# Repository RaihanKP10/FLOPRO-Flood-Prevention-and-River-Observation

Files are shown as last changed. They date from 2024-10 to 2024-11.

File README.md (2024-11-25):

# FLOPRO : Flood Prevention and River Observation

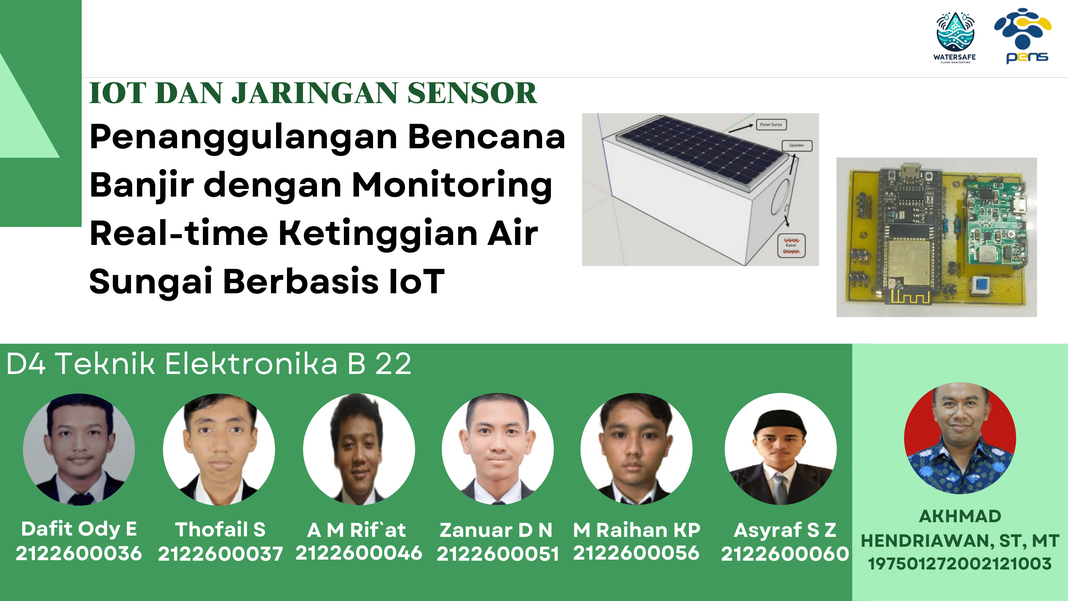
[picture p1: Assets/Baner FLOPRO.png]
Logo FLOPRO


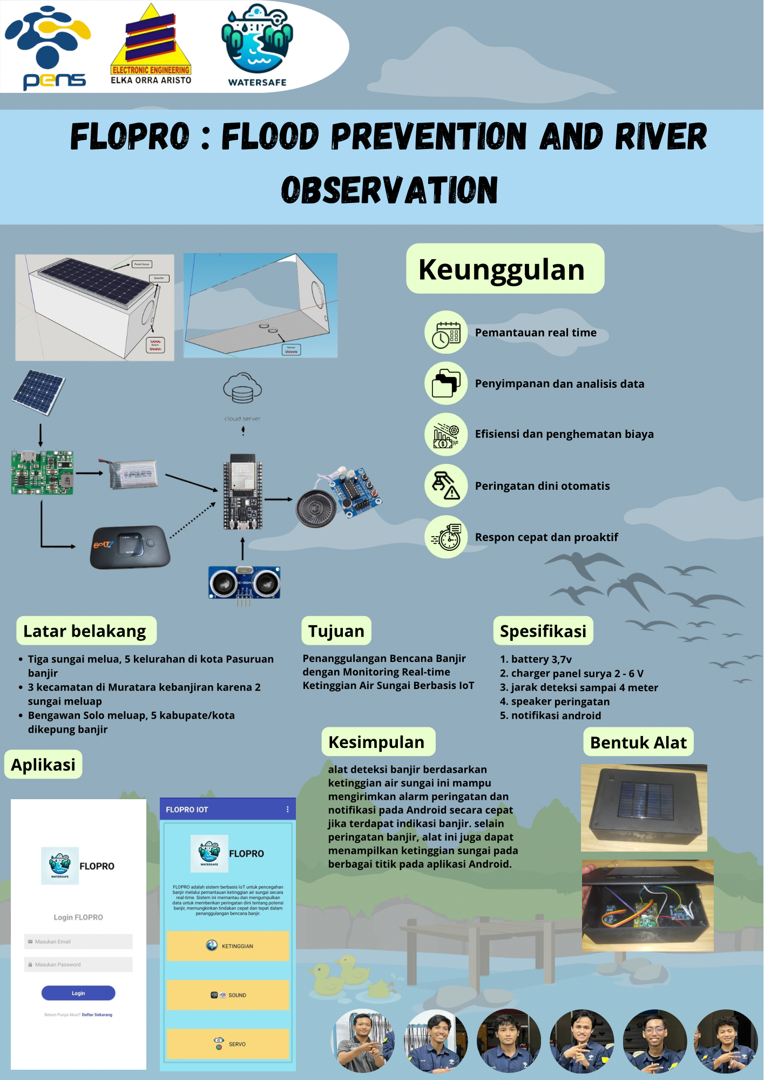
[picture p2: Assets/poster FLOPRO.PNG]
Logo FLOPRO


Proyek ini adalah Sistem Pemantauan Ketinggian Air Sungai yang menggunakan teknologi IoT untuk memberikan peringatan banjir secara real-time dengan mengukur ketinggian air sungai. Sistem ini dirancang untuk membantu manajemen bencana banjir dengan memberikan notifikasi kepada pemerintah daerah dan masyarakat tentang peningkatan ketinggian air, sehingga tindakan pencegahan dapat dilakukan sebelum banjir terjadi.

IoT dan Jaringan Sensor - [PROGRAM STUDI TEKNIK ELEKTRONIKA](https://elektronika.pens.ac.id/) - [POLITEKNIK ELEKTRONIKA NEGERI SURABAYA](https://www.pens.ac.id/)

`DOSEN PENGAMPU : Akhmad Hendriawan ST, MT`

`NIP. 197501272002121003`

## Daftar Isi
- [Fitur](https://github.com/RaihanKP10/FLOPRO-Flood-Prevention-and-River-Observation/blob/main/README.md#fitur)
- [Anggota Tim](https://github.com/RaihanKP10/FLOPRO-Flood-Prevention-and-River-Observation/blob/main/README.md#anggota-tim)
- [Demonstrasi Kalibrasi Sensor](https://github.com/RaihanKP10/FLOPRO-Flood-Prevention-and-River-Observation/blob/main/README.md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)

## Fitur
- **Pemantauan Real-Time**: Mengukur ketinggian air sungai secara terus-menerus menggunakan sensor.
- **Transmisi Data**: Mengirimkan data ke server cloud melalui perangkat IoT.
- **Sistem Peringatan Banjir**: Memberikan peringatan ketika ketinggian air melebihi ambang batas.
- **Antarmuka Web dan Mobile**: Menampilkan data dan peringatan pada dasbor yang mudah digunakan.
- **Penyimpanan Data**: Menyimpan data untuk analisis dan prediksi.
- **Pengaturan Ambang Batas**: Menyesuaikan ambang batas sesuai tingkat risiko.

## Anggota Tim

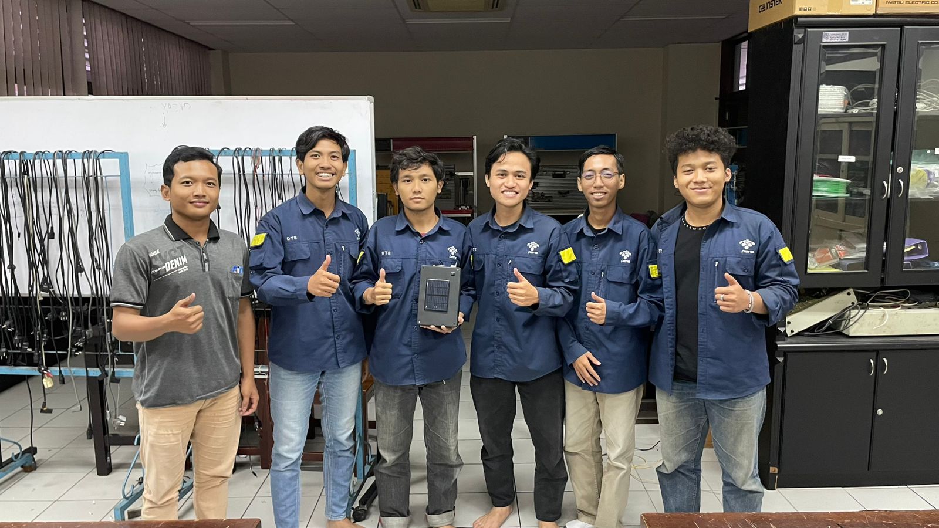
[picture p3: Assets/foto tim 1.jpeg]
FotoTim

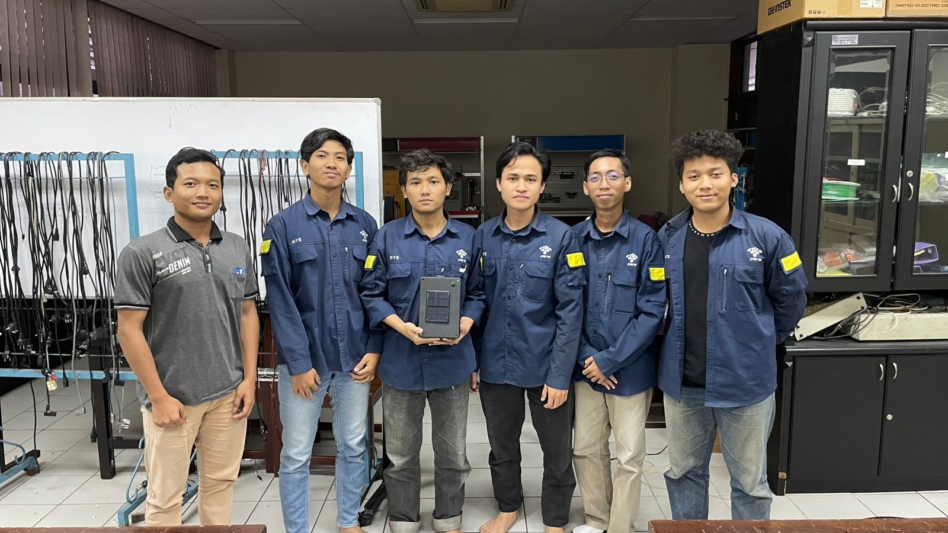
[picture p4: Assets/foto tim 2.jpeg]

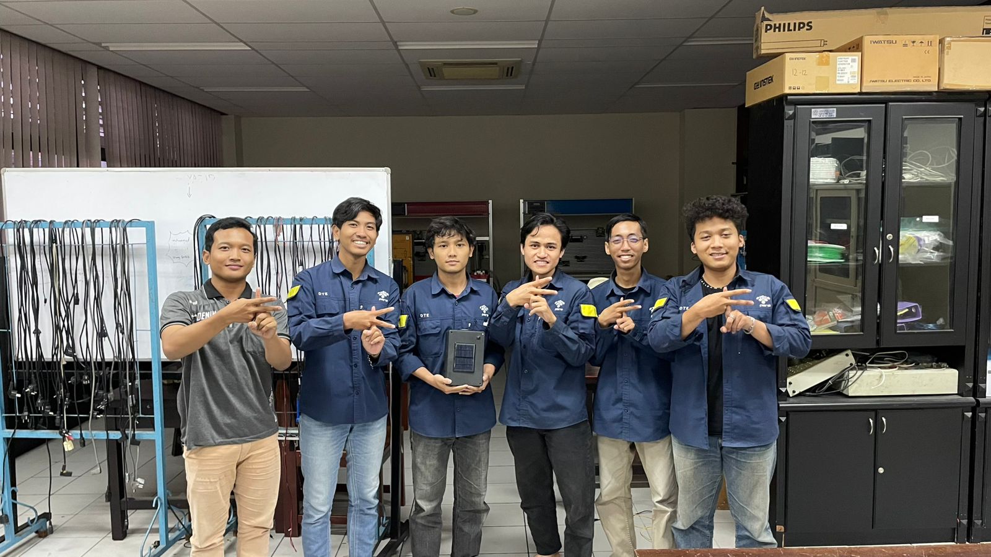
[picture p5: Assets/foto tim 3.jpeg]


| Foto | NRP | Nama | Jobdesk | Akun |
|---|---|---|---|---|
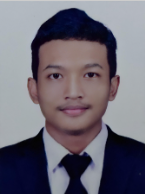
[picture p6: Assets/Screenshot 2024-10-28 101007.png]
Foto Ody
|  | 2122600036 | Dafit Ody Endriantono | UI/UX Designer | [Ody](https://github.com/DafitOdy-In) |
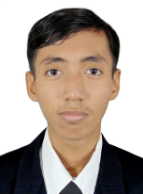
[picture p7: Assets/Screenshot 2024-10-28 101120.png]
Foto Thofail
|  | 2122600037 | Thofail Syakirudin | Hardware | [Thofail](https://github.com/DzavanTS) |
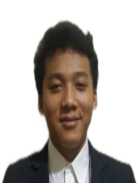
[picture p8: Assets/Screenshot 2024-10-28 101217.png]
Foto Rif'at
|  | 2122600046 | Ahmad Miftahur Rif'at | Mechanical | [Rif'at](https://github.com/AatForUX) |
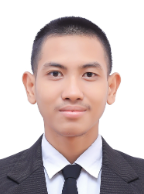
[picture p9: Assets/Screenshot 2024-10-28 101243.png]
Foto Zanuar
|  | 2122600051 | Zanuar Dwi Novaliyanto | Mechanical | [Zanuar](https://github.com/ZanuarDwiNovaliyanto) |
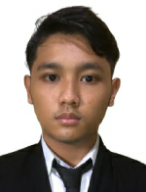
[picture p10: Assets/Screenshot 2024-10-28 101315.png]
Foto Raihan
|  | 2122600056 | Moch Raihan Kemal P | Software | [Raihan](https://github.com/RaihanKP10) |
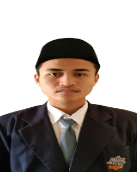
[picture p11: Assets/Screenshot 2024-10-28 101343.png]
Foto Asyraf
|  | 2122600060 | Asyraf Sulthan Zaky | Project Manager | [Asyraf](https://github.com/AsyrafSinclair) |

## Hardware Desain
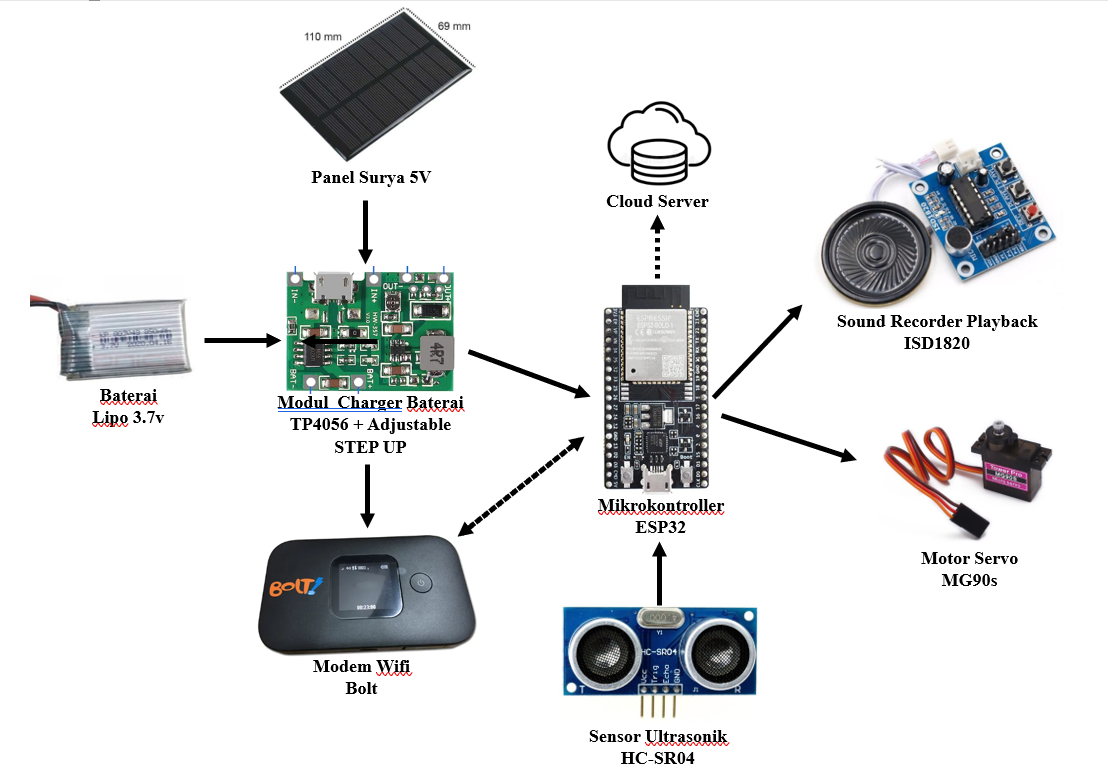
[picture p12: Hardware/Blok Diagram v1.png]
Desain Hardware


Alat ini mengukur ketinggian air dengan sensor ultrasonik HCSR-04 dan mengirimkan data ke server untuk ditampilkan melalui aplikasi. Ketika ketinggian mendekati ambang batas, sistem memicu servo untuk membuka pintu air di bendungan. Karena alat berada di luar ruangan, data dikirim melalui modem WiFi, dan energi diperoleh dari panel surya mini yang disimpan dalam baterai.

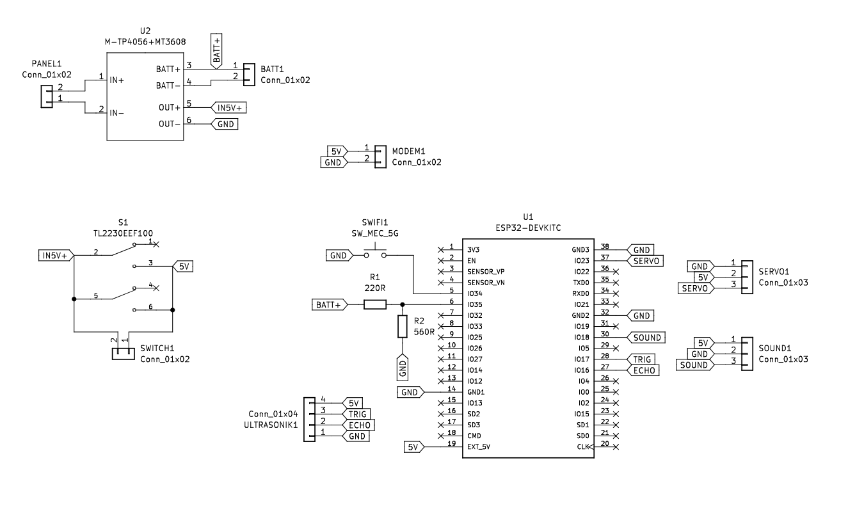
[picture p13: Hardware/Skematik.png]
Hardware Skematik Desain

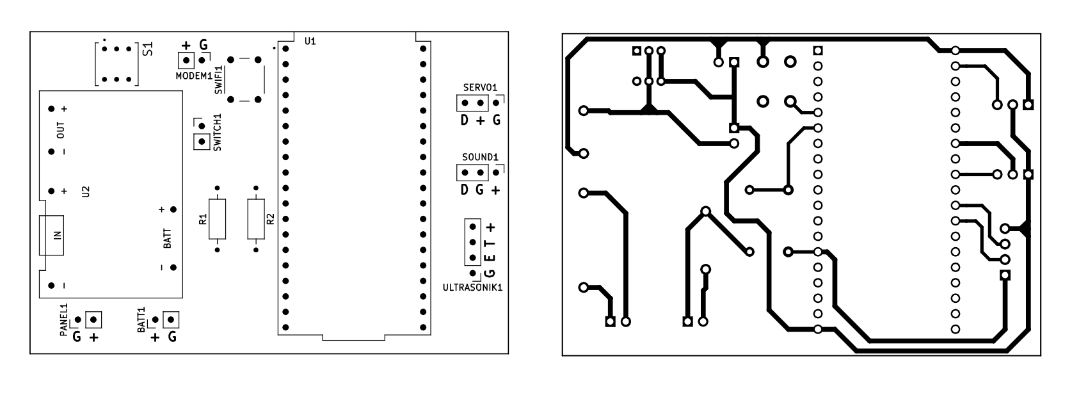
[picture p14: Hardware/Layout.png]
Hardware Layout Desain

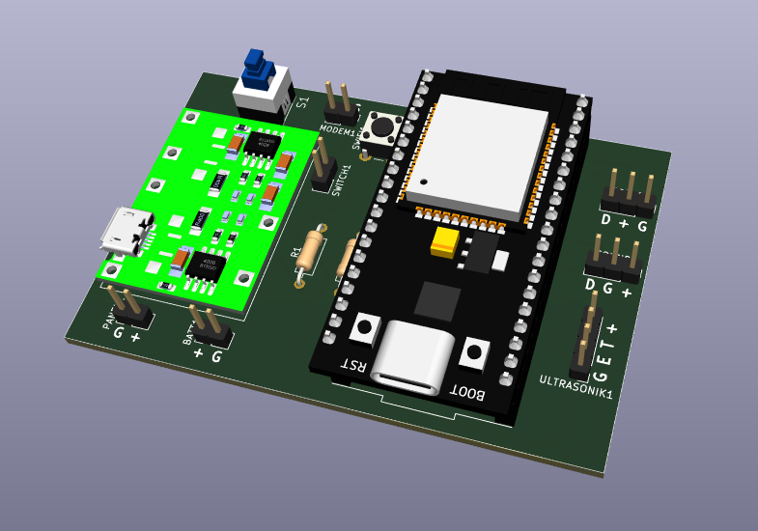
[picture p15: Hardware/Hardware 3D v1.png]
Desain 3D Hardware

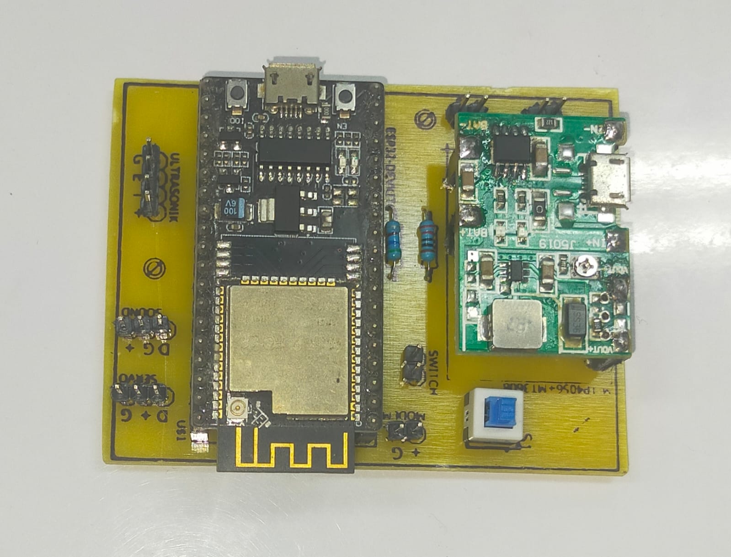
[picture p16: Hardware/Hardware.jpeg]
Desain Hardware


---

---
## PPT FLOPRO

https://www.canva.com/design/DAGU0XxpfDs/OkEMPqyUYkoWt_qYXgOqGQ/edit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

---

---

## Demonstrasi Kalibrasi Sensor
#### 1. Link Demonstrasi Kalibrasi Sensor HCSR04 :

https://github.com/user-attachments/assets/5eed2dfb-3297-49b0-9c64-bf10c1c43c4e
   
https://youtube.com/shorts/4SDvYGCIjRk?feature=share
   
Kalibrasi sensor HC-SR04 adalah proses penyesuaian sensor ultrasonik ini untuk meningkatkan akurasi dalam mengukur jarak. Sensor HC-SR04 bekerja dengan mengirimkan gelombang ultrasonik dari pemancar (transmitter) dan menghitung waktu yang dibutuhkan oleh gelombang tersebut untuk memantul kembali ke penerima (receiver) setelah mengenai suatu objek. Dengan menggunakan kecepatan suara sebagai acuan, sensor ini dapat menghitung jarak objek berdasarkan waktu tempuh gelombang.

#### 2. Link Demonstrasi Kalibrasi Servo MG90s :

https://github.com/user-attachments/assets/9af5d12e-d331-4dda-a720-6778b383e7d6
   
https://youtube.com/shorts/B2ZGl9izdCo?feature=share
   
Kalibrasi servo MG90S adalah proses penyetelan servo motor ini untuk memastikan bahwa sudut putarannya akurat sesuai dengan sinyal kontrol yang diterima. Servo MG90S adalah servo motor kecil yang banyak digunakan dalam proyek robotika dan sistem kontrol, dengan kemampuan untuk berputar pada sudut tertentu berdasarkan sinyal PWM (Pulse Width Modulation) yang diterimanya.

#### 3. Link Demonstrasi Kalibrasi Mini Speaker :

https://github.com/user-attachments/assets/9ce2ebc6-c74e-48cd-b972-0ce2e92cbb17
   
https://youtu.be/lZPbhcjN7L0
   
Kalibrasi mini speaker adalah proses penyesuaian output suara dari speaker kecil untuk mencapai kualitas audio yang optimal sesuai kebutuhan. Mini speaker sering digunakan dalam perangkat elektronik portabel dan sistem suara kecil. Kalibrasi pada mini speaker bertujuan untuk memastikan bahwa suara yang dihasilkan sesuai dengan frekuensi yang diinginkan, volume yang tepat, serta tanpa distorsi.

#### 4. Link Demonstrasi Koneksi OTA :

https://github.com/user-attachments/assets/de8e1125-ee2f-4111-9aa6-75a2dc0249be

https://youtu.be/pMJeovFwK_Y?si=bnQbwsUD5YesixBR

Demonstrasi Koneksi OTA (Over-the-Air): Pada bagian pertama, kita akan melihat langkah-langkah dalam mengatur koneksi OTA. Ini memungkinkan perangkat untuk menerima pembaruan firmware secara nirkabel, memudahkan Anda mengelola pembaruan sistem tanpa perlu koneksi fisik ke perangkat.

#### 5. Link Demonstrasi Pembuatan Firmware :

https://github.com/user-attachments/assets/bfa29fa6-aab0-4fcf-a872-c59f6ed02e61

https://youtu.be/gWfn4EX8Wdg?si=ucNGiH2ZgVsit7tk

Demonstrasi Pembuatan Firmware: Berikutnya, kita akan mendalami proses pembuatan firmware yang sesuai dengan perangkat IoT Anda. Di sini, kita akan membahas cara menyusun kode, mengompilasi, hingga mengunggah firmware yang telah dibuat.

#### 6. Link Demonstrasi Sistem Monitoring Baterai :

https://github.com/user-attachments/assets/31b2b31e-45c3-4f26-8fa8-c767af66bc61

https://youtu.be/-h_9dVcLRwE?si=lmYOK9LiICJJzn_O

Demonstrasi Sistem Monitoring Baterai: Terakhir, kita akan mengimplementasikan sistem monitoring baterai untuk memantau status baterai perangkat. Monitoring ini sangat penting agar kita dapat memprediksi daya tahan perangkat dan memastikan bahwa perangkat selalu aktif sesuai kebutuhan.

#### 7. Link Demonstrasi Wifi Manager:

https://github.com/user-attachments/assets/3f8c9bdd-fb43-4b81-9738-53641b77a450

https://youtu.be/Md__u2JPdc4?si=srvmaIoYwEQb-n4l

Konfigurasi Wifi Manager FLOPRO untuk Proyek IoT dan Jaringan Sensor: Bagian pertama tutorial ini akan mengulas proses konfigurasi Wifi Manager untuk perangkat FLOPRO. Langkah ini penting agar perangkat dapat terhubung dengan jaringan WiFi yang ada secara fleksibel dan otomatis, memungkinkan koneksi yang efisien di berbagai lokasi.

#### 8. Link Demonstrasi Simulasi FLOPRO Pada Bak Mandi (Mengilustrasikan Sungai) :

https://github.com/user-attachments/assets/f5d06698-10ce-430e-9a92-0ce6799bd68e

https://youtu.be/32SNqkH3HE4?si=-2HCcUrE732MUAwt

Simulasi Demo FLOPRO pada Bak Mandi (Mengilustrasikan Sungai): Di bagian kedua, kita akan melakukan simulasi dengan bak mandi sebagai representasi sungai untuk memperlihatkan bagaimana sistem FLOPRO bekerja dalam mengukur dan memantau kualitas air. Sistem ini menggunakan sensor untuk membaca data kualitas air secara real-time, yang nantinya dapat diakses dari jarak jauh.

#### 9. Link Demonstrasi Alat + Aplikasi FLOPRO :

https://github.com/user-attachments/assets/4c1feaa1-9933-437e-9100-74239c586628

https://youtu.be/wIVfHC5TFvU

Demonstrasi alat dan aplikasi FLOPRO menampilkan cara penggunaan dan fitur utama FLOPRO untuk mendukung aktivitas pengguna. Video ini menunjukkan langkah-langkah operasional alat, mulai dari instalasi hingga integrasi dengan aplikasi FLOPRO, yang memungkinkan kontrol dan pemantauan data secara real-time. Dengan demonstrasi ini, pengguna dapat memahami bagaimana FLOPRO bekerja secara praktis untuk meningkatkan efisiensi dan efektivitas alat FLOPRO

#### 10. Link Demonstrasi Aplikasi FLOPRO :

https://github.com/user-attachments/assets/227b0415-c697-41e6-8797-6734db90a10a

https://youtu.be/Y9suIjy_hSk

Demonstrasi aplikasi FLOPRO memperlihatkan fitur-fitur utama dan cara menggunakan aplikasi untuk memaksimalkan fungsinya. Video ini menjelaskan langkah-langkah cara daftar akun dan login akun, serta cara menggunakan aplikasi

---

---
## Tampilan Aplikasi FLOPRO
#### 1. Register :
Register

Tampilan aplikasi FLOPRO bagian Register dirancang untuk memudahkan pengguna baru dalam membuat akun dan mengakses layanan aplikasi. Di halaman ini, pengguna akan diminta untuk mengisi informasi dasar seperti nama, email, dan kata sandi. Tampilan yang sederhana dan intuitif memastikan proses registrasi berjalan cepat dan mudah. Ada juga tombol Submit untuk menyelesaikan proses pendaftaran serta petunjuk tambahan yang membantu pengguna dalam mengisi data dengan benar.

### 2. Login :
Login

Tampilan aplikasi FLOPRO bagian Login dirancang untuk memudahkan pengguna masuk ke akun mereka dengan cepat dan aman. Di halaman ini, terdapat kolom untuk memasukkan email dan kata sandi, dengan tombol Login untuk melanjutkan ke halaman utama aplikasi. Tampilan yang sederhana dan bersih membantu pengguna fokus saat mengisi informasi. Ada juga opsi Forgot Password bagi pengguna yang lupa kata sandi, serta pilihan untuk mendaftar bagi pengguna baru yang belum memiliki akun.

### 3. Dashboard :
Dashboard

Tampilan aplikasi FLOPRO pada bagian Dashboard memberikan akses cepat dan ringkas ke informasi utama serta fitur-fitur penting. Di halaman ini, pengguna dapat melihat ringkasan data secara real-time, status perangkat yang terhubung, serta grafik atau statistik yang relevan dengan aktivitas mereka. Dashboard dirancang dengan antarmuka yang intuitif dan visual yang menarik, sehingga memudahkan pengguna dalam memantau, mengontrol, dan mengakses fitur aplikasi lainnya. Navigasi yang sederhana memungkinkan pengguna untuk berpindah ke menu lain dengan mudah dan efisien.

### 4. Demo Aplikasi FLOPRO Pembacaan Data Sensor :
https://github.com/user-attachments/assets/2c82f72f-5ee5-42d2-a93c-78d115699a81

### 5. Demo Aplikasi FLOPRO Register & Login Akun :
https://github.com/user-attachments/assets/8cda75ff-3960-4abb-a7de-a9cabbc41a08

---

---
## Video Presentasi & Iklan FLOPRO
#### 1. Presentasi :
https://youtu.be/c4BK9ON1-bA?si=03641uwP3lWksoRz

Video ini menampilkan presentasi lengkap dari proyek IoT dan Jaringan Sensor dengan nama FLOPRO yang dikerjakan oleh tim mahasiswa D4 Teknik ELektronika B. Presentasi mencakup beberapa segmen utama:

Latar Belakang Proyek
Penjelasan awal tentang motivasi dan tujuan pembuatan alat ini. Proyek ini dirancang untuk mengatasi masalah tertentu dengan memanfaatkan teknologi IoT dan jaringan sensor.

Demo Hardware dan Aplikasi

Langkah-langkah instalasi dan penggunaan perangkat keras.
Tampilan langsung dari sensor yang digunakan dan bagaimana data dikumpulkan.
Demonstrasi aplikasi yang dikembangkan untuk memonitor data dari sensor secara real-time melalui platform IoT.
Penjelasan Isi GitHub

Struktur repositori GitHub yang menyimpan seluruh kode sumber dan dokumentasi proyek.
Penjelasan tentang file utama, cara kerja program, dan instruksi penggunaan yang tersedia di GitHub.

#### 2. Iklan :
https://youtube.com/shorts/QswNNAhAtY0?si=gQIX3H-hSb-66b26

Video ini menampilkan iklan produk dari proyek IoT dan Jaringan Sensor dengan nama FLOPRO_yang dikerjakan oleh tim mahasiswa D4 Teknik Elektronika B

&copy; 2024 FLOPRO. All rights reserved.

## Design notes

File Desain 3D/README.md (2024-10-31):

# Desain 3D FLOPRO

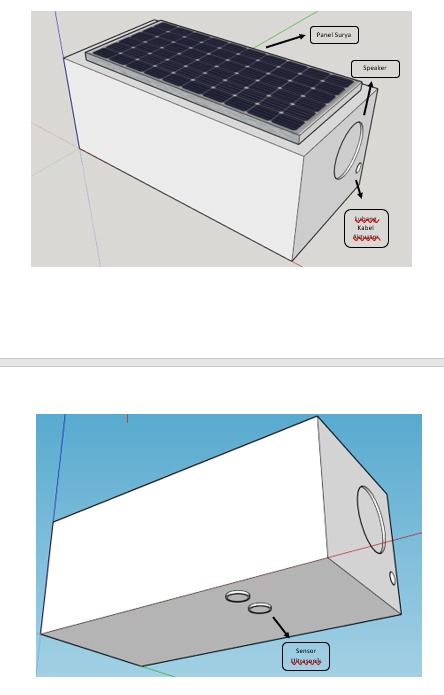
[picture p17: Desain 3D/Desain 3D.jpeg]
Desain 3D


Gambar yang ditampilkan menunjukkan desain perangkat berbentuk kotak yang dilengkapi dengan panel surya di bagian atas untuk sumber daya dan speaker di samping. Pada bagian bawah, terdapat sensor yang kemungkinan digunakan untuk mendeteksi parameter lingkungan seperti ketinggian air atau jarak, tergantung jenis sensornya. Desain perangkat ini memungkinkan sensor untuk melakukan pengukuran langsung terhadap permukaan di bawahnya. Dua lubang kecil di sekitar sensor mungkin berfungsi sebagai ventilasi atau akses untuk komponen lain. Kombinasi panel surya, sensor, dan speaker menunjukkan bahwa perangkat ini dirancang untuk pemantauan lingkungan secara mandiri.

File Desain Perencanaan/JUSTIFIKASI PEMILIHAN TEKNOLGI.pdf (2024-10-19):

JUSTIFIKASI PEMILIHAN TEKNOLGI

1. Sensor Ultrasonik HC-SR04
Sensor ini dipilih karena kemampuannya mengukur ketinggian air dengan cukup akurat menggunakan gelombang ultrasonik. HC-SR04 sangat sesuai untuk proyek ini karena ketahanannya terhadap kondisi lingkungan yang kurang ideal, seperti kelembaban dan hujan, sehingga memungkinkan pengukuran jarak secara stabil di berbagai kondisi.
2. Mikrokontroler ESP32
ESP32 dipilih karena memiliki fitur konektivitas Wi-Fi dan Bluetooth, serta daya pemrosesan yang lebih baik dibandingkan mikrokontroler lainnya, seperti ESP8266. Dengan dukungan Wi-Fi, ESP32 dapat mengirimkan data ketinggian air secara real-time ke server cloud, menjadikannya solusi ideal untuk pemantauan jarak jauh. Kemampuan ini penting dalam sistem monitoring yang memerlukan pengiriman data secara kontinu.
3. Protokol Komunikasi MQTT (Message Queuing Telemetry Transport)
Protokol MQTT digunakan untuk mengirimkan data ketinggian air secara efisien dan real-time. Protokol ini dipilih karena sifatnya yang ringan dan hemat energi, sehingga sangat cocok untuk perangkat seperti ESP32 yang sering beroperasi di lokasi yang sulit dijangkau dan memiliki keterbatasan daya.
4. Penyimpanan Cloud dengan MySQL
Data ketinggian air disimpan di cloud menggunakan database MySQL. MySQL menyediakan struktur penyimpanan data yang terorganisir, yang memudahkan akses serta analisis data historis.
5. Keamanan Data
Data yang dikirim dari ESP32 ke server cloud dienkripsi untuk menjaga keamanan dan melindungi informasi sensitif dari potensi ancaman atau serangan pihak luar.
6. Akses Melalui Antarmuka Web dan Mobile
Pengguna dapat dengan mudah mengakses data ketinggian air dan menerima peringatan potensi banjir melalui aplikasi berbasis web dan mobile. Hal ini sangat membantu bagi pihak pemerintah maupun masyarakat umum dalam memantau situasi secara langsung.

Kesimpulan:
Pemilihan Sensor Ultrasonik HC-SR04 dan Mikrokontroler ESP32 merupakan solusi yang tepat untuk sistem pemantauan ketinggian air secara real-time. Kombinasi teknologi ini memungkinkan pengoperasian yang efisien, aman, dan handal, didukung dengan penyimpanan data berbasis cloud yang memastikan akses dan analisis data yang mudah serta terstruktur.

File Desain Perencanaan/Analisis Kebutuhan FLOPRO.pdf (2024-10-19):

ANALISIS KEBUTUHAN SISTEM

Dalam proses perencanaan, perancangan, hingga implementasi sistem FLOPRO,

diperlukan berbagai aspek penting yang mendukung terciptanya inovasi baru ini. Beberapa

kebutuhan utama yang harus dipenuhi dalam pengembangan sistem FLOPRO dapat dijelaskan

sebagai berikut :

1. Kebutuhan Komponen

Untuk komponen yang digunakan dalam sistem FLOPRO dapat dijelaskan sebagai

berikut ini :

No. | Nama Komponen | Deskripsi | Pin Out ESP32 | Fungsi
1 | Sensor Ultrasonik | Sensor Ultrasonik HC-SR04 | VCC 5V dan GND Trigger : GPIO 7 Echo : GPIO 6 | Untuk mendeteksi dan membaca water level pada sungai
2 | Sound Recorder | Sound Recorder Playback ISD1820 | VCC 5V dan GND Data : GPIO 8 | Untuk mengeluarkan suara peringatan
3 | Motor Servo | Motor Servo MG90s | VCC 5V dan GND Data : GPIO 23 | Menggerakkan pintu saluran air sebagai aktuator sistem
4 | ESP 32 | Mikrokontroller ESP 32 | - | Menjalankan tugas-tugas tertentu dan digunakan dalam perangkat elektronik untuk mengontrol berbagai fungsi.
5 | Baterai | Baterai LiPo 3,7v | Pin -+ terhubung ke modul Charger | Memberikan supply tegangan pada sistem
6 | Modul Charger Baterai | Modul Charger Baterai TP4056 + Adjustable Step-Up | Pin INPUT daya terhubung dengan Panel Surya | Berfungsi mengisi tegangan pada baterai

7 | Panel Surya | Panel Surya 5V | PIN out tersambung dengan Modul Charger | Merubah energi matahari menjadi energi listrik
8 | Cloud Server | Ruang penyimpanan data | - | Menyimpan data yang didapat untuk diolah
9 | Modem WiFi | Modem WiFI Bolt | - | Memberika jaringan komunikasi ESP
2. Kebutuhan 3D Design

Untuk memberikan gambaran visual yang jelas mengenai sistem FLOPRO, dibuat model

realistis dari produk ini berdasarkan konsep yang telah dirancang sebelumnya menggunakan

desain 3D.

3. Kebutuhan Monitoring sistem FLOPRO melalui aplikasi (software)

Dalam upaya memudahkan akses monitoring, dikembangkan software yang menyajikan

informasi terkait ketinggian air sungai secara real-time serta riwayat perubahan ketinggian air..

4. Kebutuhan Desain UI/UX aplikasi FLOPRO

Agar aplikasi FLOPRO mudah digunakan dan nyaman bagi pengguna, dirancang desain

UI/UX yang menarik dan konsisten. Desain ini bertujuan untuk mengoptimalkan alur

penggunaan aplikasi serta memudahkan interaksi pengguna..

5. Kebutuhan analisa data sistem FLOPRO

Data yang dikumpulkan oleh sensor akan dianalisis untuk menghasilkan laporan yang

mencakup kesimpulan dan rekomendasi optimalisasi sistem. Hasil analisis ini diharapkan

memberikan wawasan baru untuk pengembangan lebih lanjut.

6. Komunikasi Protokol MQTT

Dalam sistem FLOPRO, protokol MQTT (Message Queuing Telemetry Transport)

digunakan untuk menghubungkan perangkat dengan platform IoT atau server. Protokol ini

mendukung komunikasi data yang efisien, real-time, dan hemat energi, memungkinkan

pemantauan dan pengendalian sistem dari jarak jauh dengan mudah..

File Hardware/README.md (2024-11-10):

## Blok Diagram
Blok Diagram

Alat ini mengukur ketinggian air dengan sensor ultrasonik HCSR-04 dan mengirimkan data ke server untuk ditampilkan melalui aplikasi. Ketika ketinggian mendekati ambang batas, sistem memicu servo untuk membuka pintu air di bendungan. Karena alat berada di luar ruangan, data dikirim melalui modem WiFi, dan energi diperoleh dari panel surya mini yang disimpan dalam baterai.

---

## Hardware Desain
Hardware Skematik Desain
Hardware Layout Desain

---

## Hardware Desain 3D
Desain 3D Hardware

---

## Hardware
Desain Hardware

---

## Pengetesan Hardware Pada Wokwi
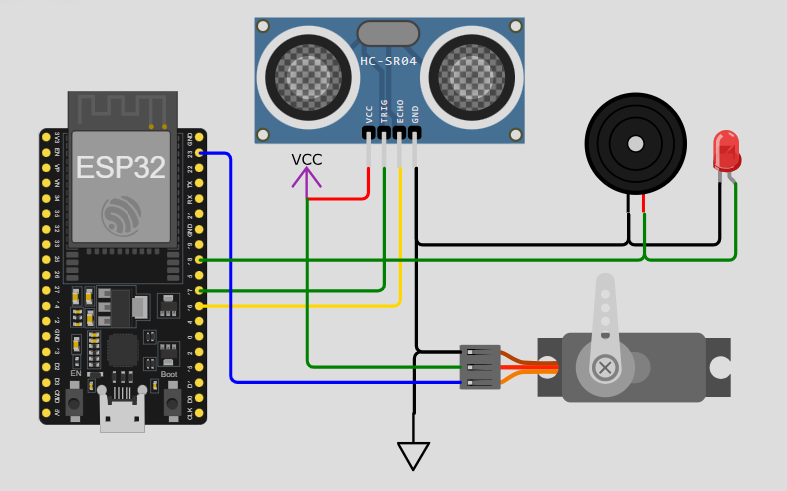
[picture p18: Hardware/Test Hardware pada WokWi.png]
Desain 3D Hardware


Pengetesan hardware dapat dilakukan pada simulasi online di Wokwi.
[Tes Hardware](https://wokwi.com/projects/411479674030035969)

---

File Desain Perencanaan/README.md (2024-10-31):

# Mind Map FLOPRO

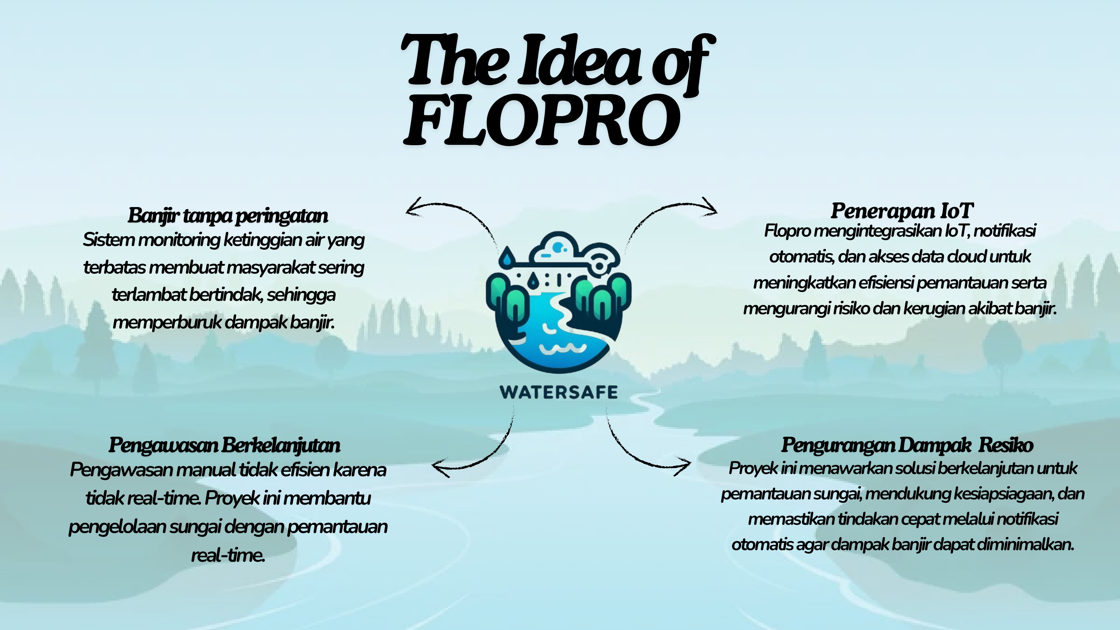
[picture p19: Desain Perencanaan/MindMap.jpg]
Mind Map


Mind map berjudul "The Idea of FLOPRO" menggambarkan proyek inovatif dalam pemantauan ketinggian air dan mitigasi banjir menggunakan teknologi IoT. Di pusatnya, ikon "WATERSAFE" menyiratkan solusi terhadap tantangan yang ada, seperti risiko banjir tanpa peringatan yang diakibatkan oleh sistem monitoring yang terbatas. FLOPRO menawarkan pengawasan berkelanjutan dengan pemantauan real-time, yang membantu pengelolaan sungai dan daerah rawan banjir. Dengan mengintegrasikan teknologi IoT, proyek ini menyediakan notifikasi otomatis dan akses data langsung, meningkatkan efisiensi pemantauan serta mengurangi risiko dan kerugian yang ditimbulkan oleh banjir. Selain itu, FLOPRO mendukung kesiapsiagaan masyarakat dengan solusi berkelanjutan yang dapat meminimalkan dampak negatif dari bencana tersebut. Secara keseluruhan, mind map ini merangkum tujuan dan manfaat FLOPRO dalam menciptakan sistem pemantauan ketinggian air yang lebih efektif dan berbasis teknologi modern.

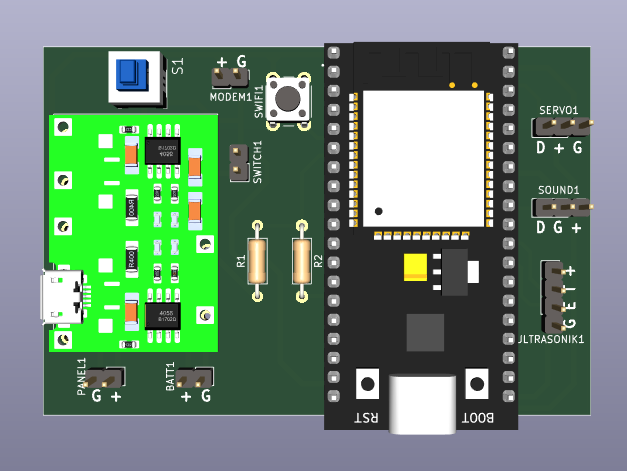
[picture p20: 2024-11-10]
Hardware/Hardware 3D tampak atas v1.png

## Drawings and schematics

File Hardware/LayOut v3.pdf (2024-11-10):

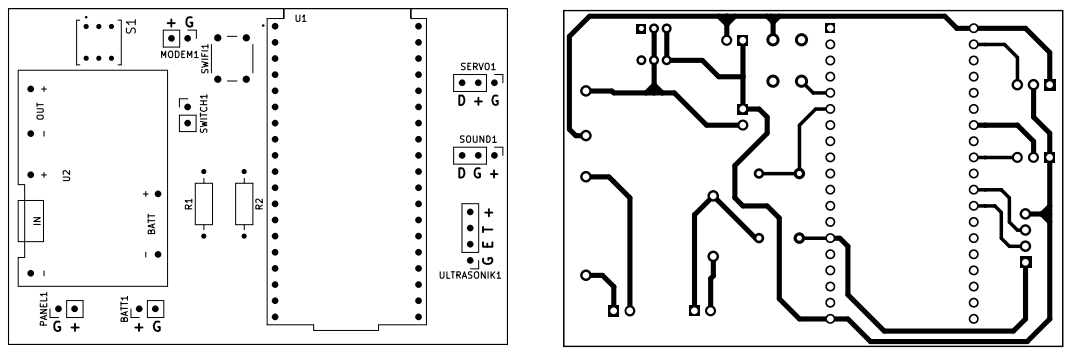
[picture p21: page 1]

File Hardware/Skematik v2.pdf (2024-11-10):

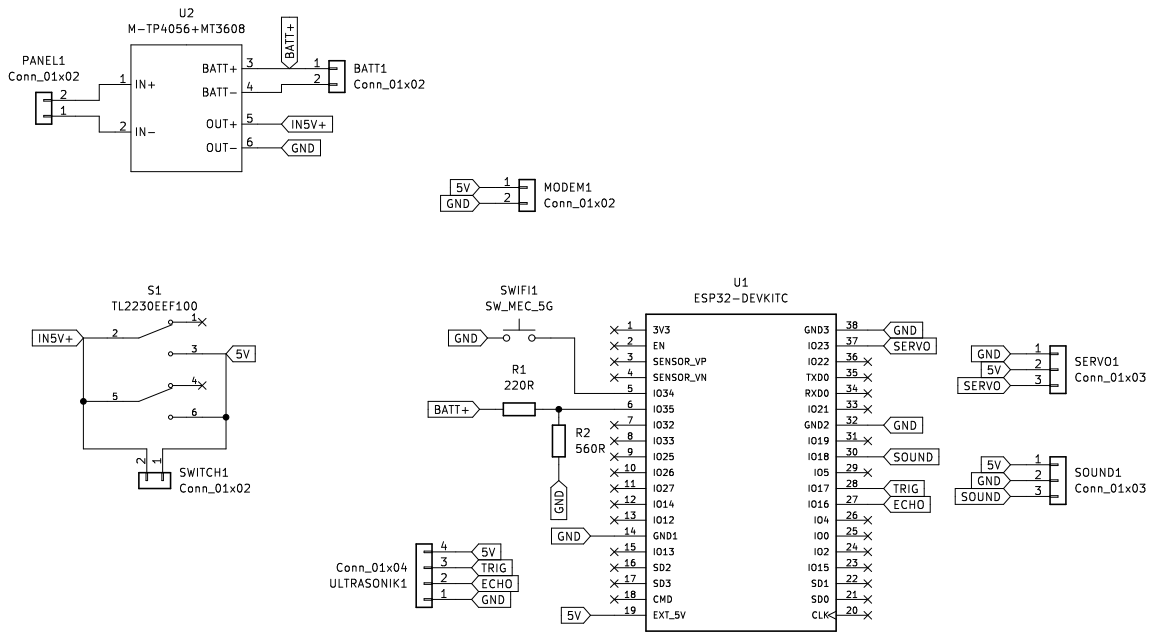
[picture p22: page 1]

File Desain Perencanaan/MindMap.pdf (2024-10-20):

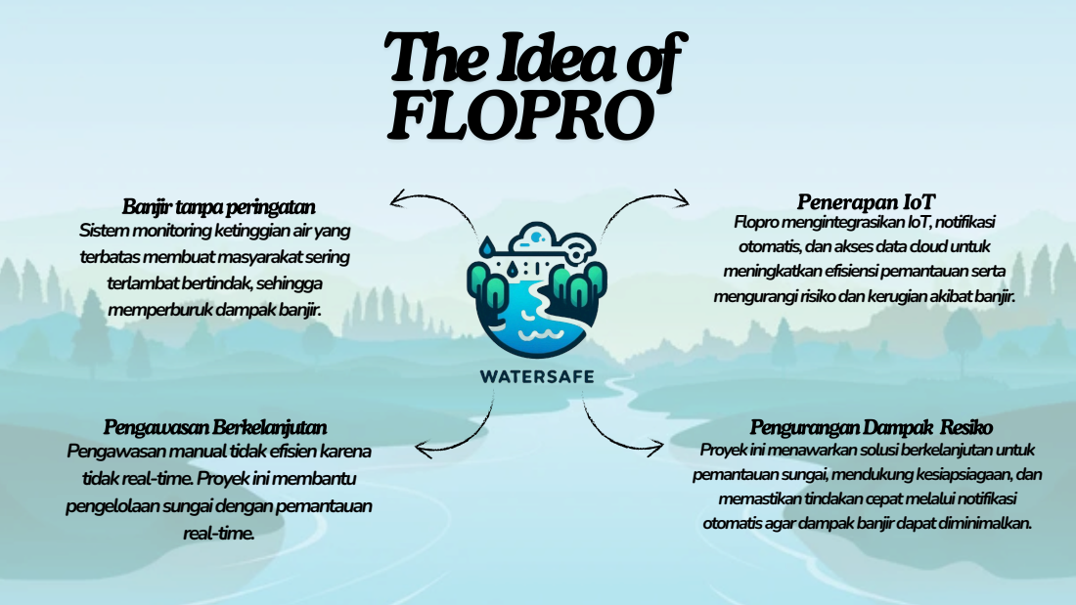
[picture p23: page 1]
real-time.; Sistemmonitoringketinggianairyang terbatasmembuatmasyarakatsering terlambatbertindak,sehingga memperburukdampakbanjir.; FlopromengintegrasikanIoT,notifikasi otomatis,danaksesdataclouduntuk meningkatkanefisiensipemantauanserta mengurangirisikodankerugianakibatbanjir.

Pengawasanmanualtidakefisienkarena
tidakreal-time.Proyekinimembantu
pengelolaansungaidenganpemantauan

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

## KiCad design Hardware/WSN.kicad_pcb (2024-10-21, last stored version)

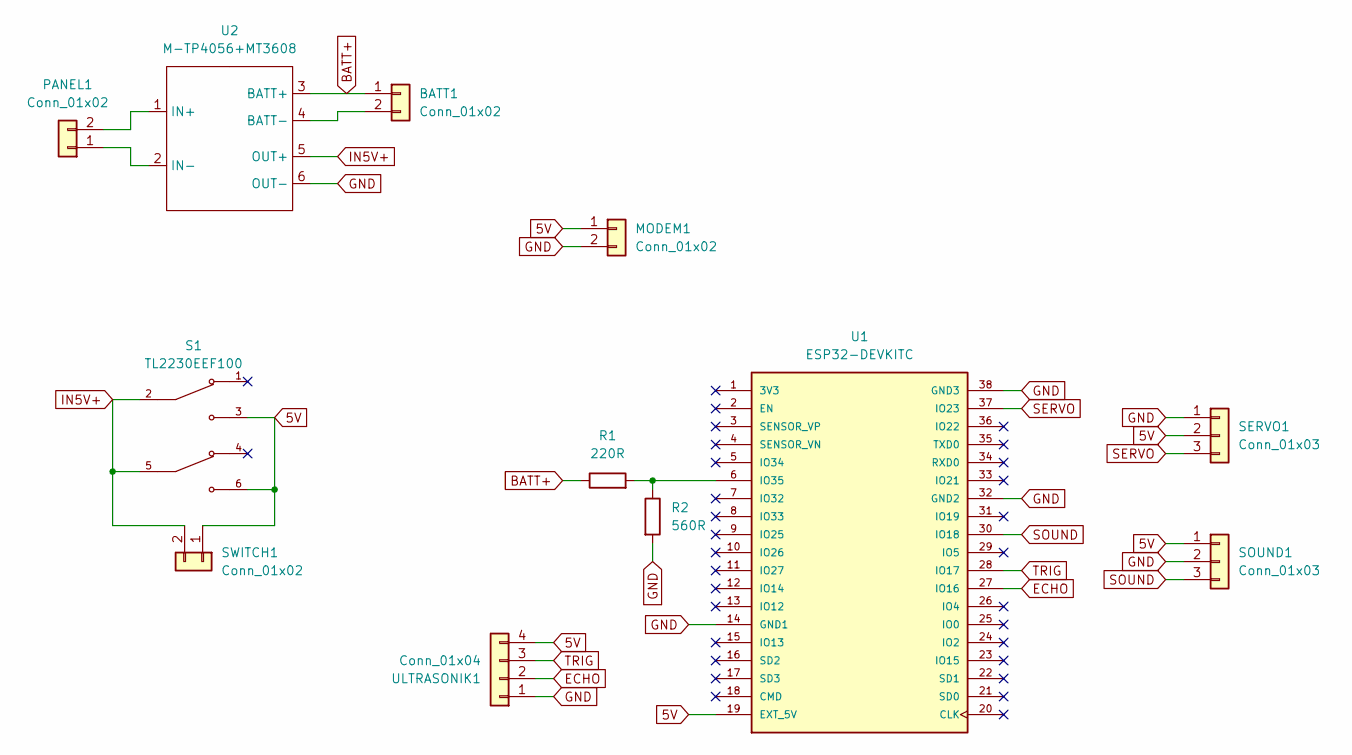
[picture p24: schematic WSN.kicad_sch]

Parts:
BATT1: Conn_01x02; PinHeader_1x02_P2.54mm_Vertical
MODEM1: Conn_01x02; PinHeader_1x02_P2.54mm_Vertical
PANEL1: Conn_01x02; PinHeader_1x02_P2.54mm_Vertical
R1: 220R; R_Axial_DIN0207_L6.3mm_D2.5mm_P10.16mm_Horizontal
R2: 560R; R_Axial_DIN0207_L6.3mm_D2.5mm_P10.16mm_Horizontal
S1: TL2230EEF100; SW_TL2230OAF140; PARTREV E
SERVO1: Conn_01x03; PinHeader_1x03_P2.54mm_Vertical
SOUND1: Conn_01x03; PinHeader_1x03_P2.54mm_Vertical
SWITCH1: Conn_01x02; PinHeader_1x02_P2.54mm_Vertical
U1: ESP32-DEVKITC; MODULE_ESP32-DEVKITC; PARTREV N/A
U2: M-TP4056+MT3608
ULTRASONIK1: Conn_01x04; PinHeader_1x04_P2.54mm_Vertical

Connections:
5V: MODEM1.1, S1.3, S1.6, SERVO1.2, SOUND1.1, SWITCH1.1, U1.19 (EXT_5V), ULTRASONIK1.4
BATT+: BATT1.1, R1.1, U2.3 (BATT+)
ECHO: U1.27 (IO16), ULTRASONIK1.2
GND: MODEM1.2, R2.2, SERVO1.1, SOUND1.2, U1.14 (GND1), U1.32 (GND2), U1.38 (GND3), U2.6 (OUT-), ULTRASONIK1.1
IN5V+: S1.2, S1.5, SWITCH1.2, U2.5 (OUT+)
unnamed: BATT1.2, U2.4 (BATT-)
unnamed: PANEL1.1, U2.2 (IN-)
unnamed: PANEL1.2, U2.1 (IN+)
unnamed: R1.2, R2.1, U1.6 (IO35)
SERVO: SERVO1.3, U1.37 (IO23)
SOUND: SOUND1.3, U1.30 (IO18)
TRIG: U1.28 (IO17), ULTRASONIK1.3

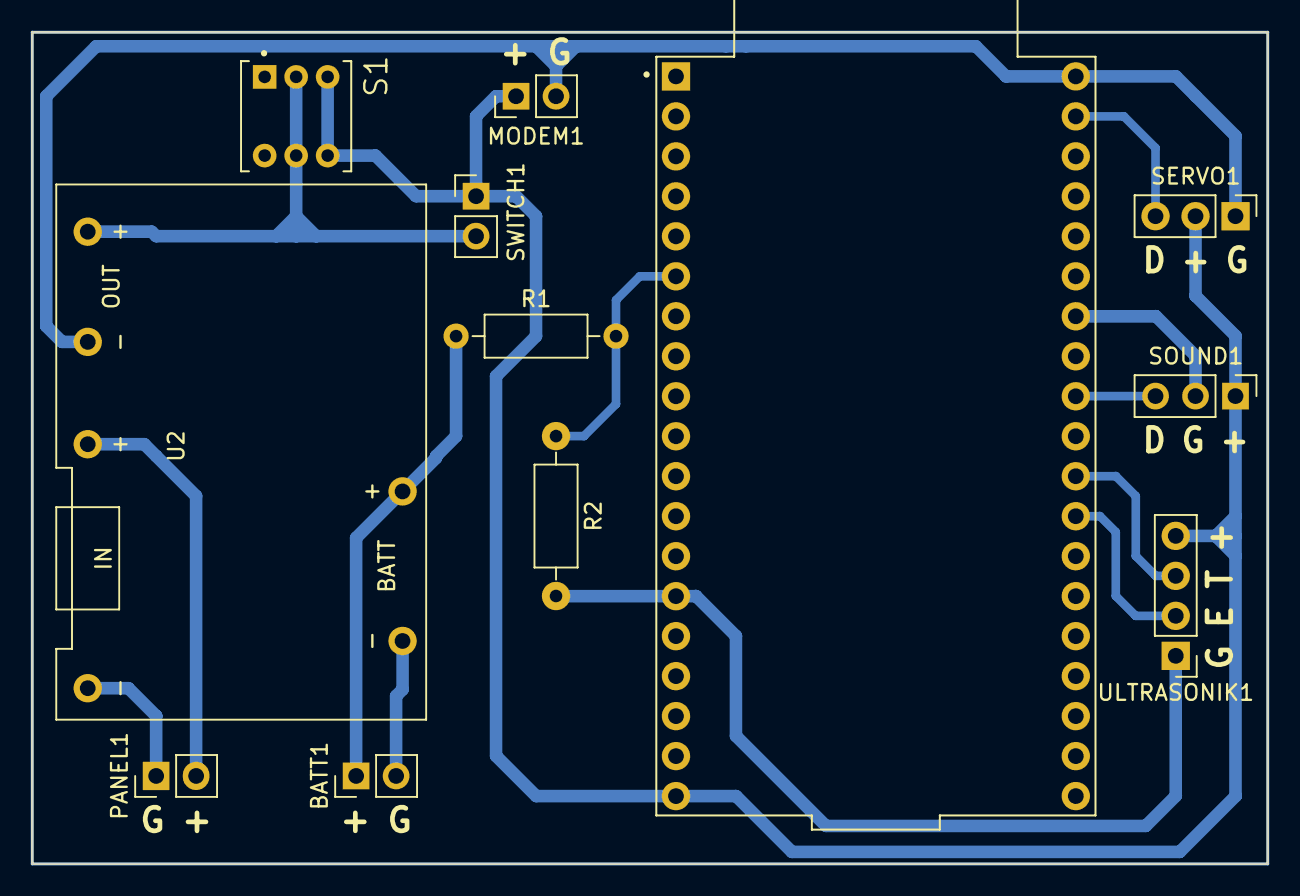
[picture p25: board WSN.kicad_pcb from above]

Board: 2 copper layers, 78.5 x 52.8 mm, 12 parts (0 on the bottom side), 12 nets.

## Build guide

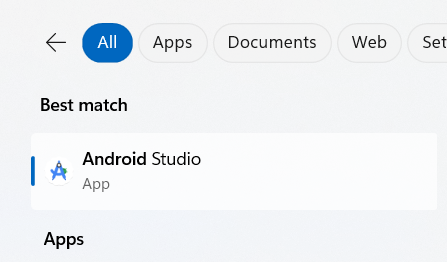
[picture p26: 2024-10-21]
Pembuatan Aplikasi/Progress 1/Penginstallan Aplikasi & Flutter/Penginstallan Android Studio.png

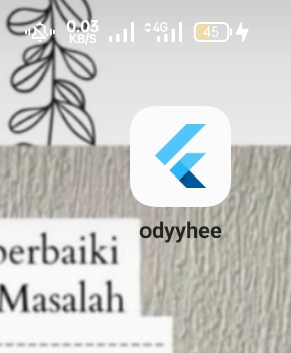
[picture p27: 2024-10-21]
Pembuatan Aplikasi/Progress 1/Penginstallan Aplikasi & Flutter/Progress Percobaan Build APK.jpeg

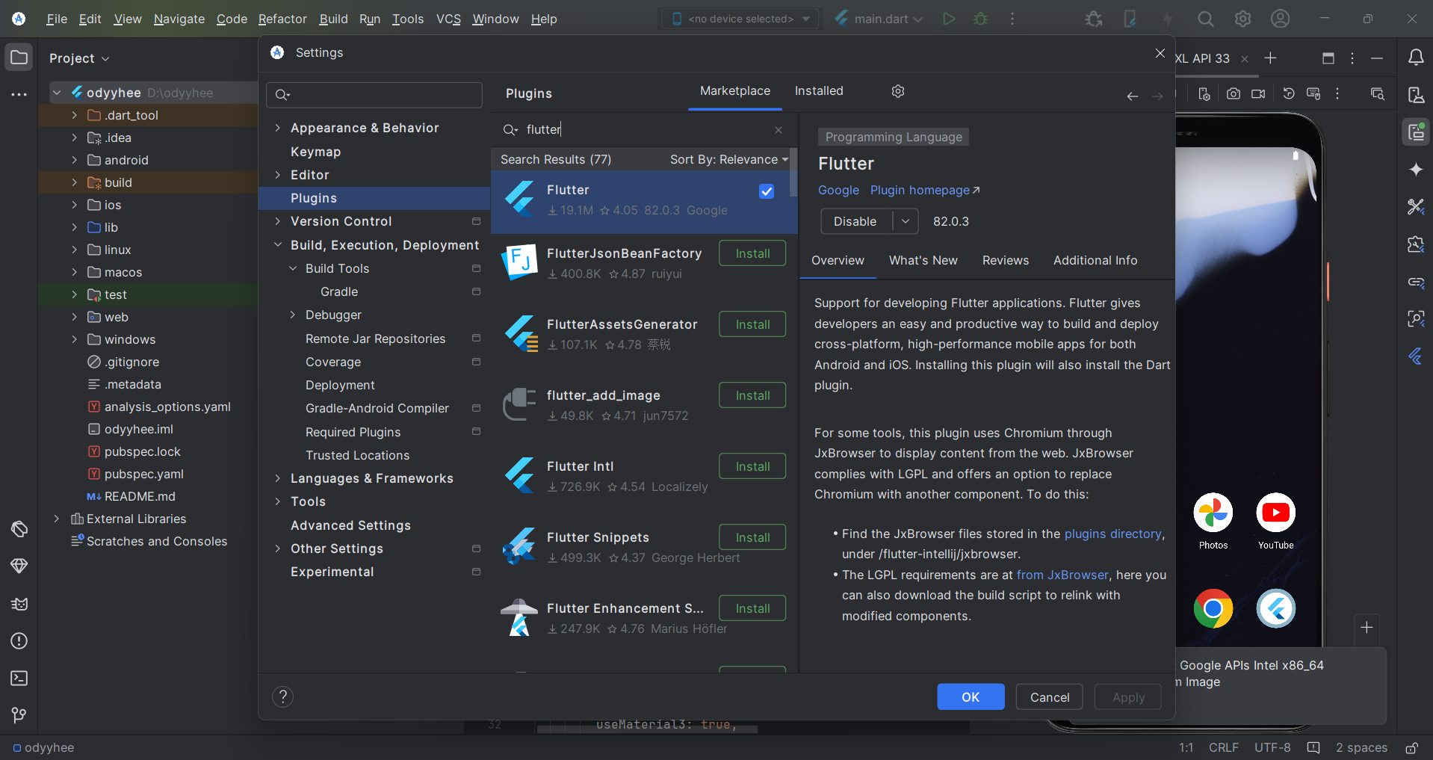
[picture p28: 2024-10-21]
Pembuatan Aplikasi/Progress 1/Penginstallan Aplikasi & Flutter/Penginstallan Flutter.png

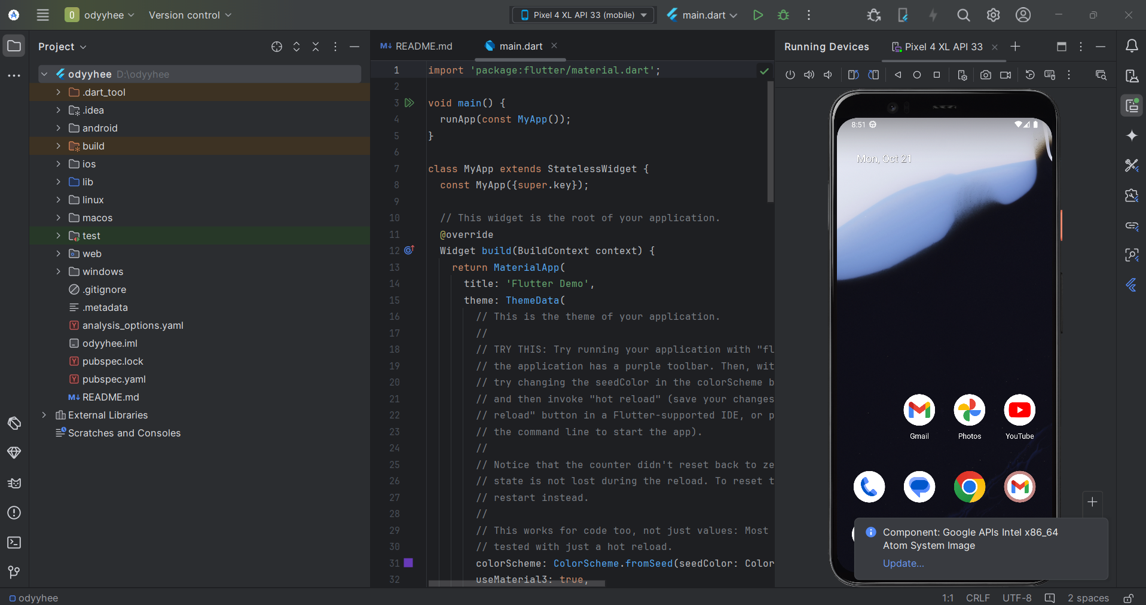
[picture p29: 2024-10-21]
Pembuatan Aplikasi/Progress 1/Penginstallan Aplikasi & Flutter/Progress Pembuatan Program Aplikasi.png

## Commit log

2024-10-12 Desain PCB
2024-10-21 Update Desain PCB
2024-10-21 Update README Desain PCB.md
2024-11-10 Add Desain Kicad
2024-11-10 Update Desain Kicad
